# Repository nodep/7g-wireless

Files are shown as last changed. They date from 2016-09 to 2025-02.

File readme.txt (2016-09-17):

This project implements a replacement wireless keyboard controller which can be plugged into the SteelSeries 7G keyboard in place of the original controller.

The controller is designed around an Atmel ATMega169A. It communicates with the USB dongle (nRF24LU1+) using the nRF24L01+ 2.4GHz radio transceiver.

With aggressive power optimizations I have achieved an average consumption of 20 μA on the keyboard controller. It can run 6 to 10 years on two low self-discharge AA batteries or a year on a single CR2032 lithium cell. The USB dongle implements a standard HID keyboard. The keyboard also has a driverless configuration menu.

The dongle code can be compiled with sdcc (Small Device C Compiler) and the keyboard controller with avr-gcc.

The controller schematic and PCB are designed with EagleCAD.

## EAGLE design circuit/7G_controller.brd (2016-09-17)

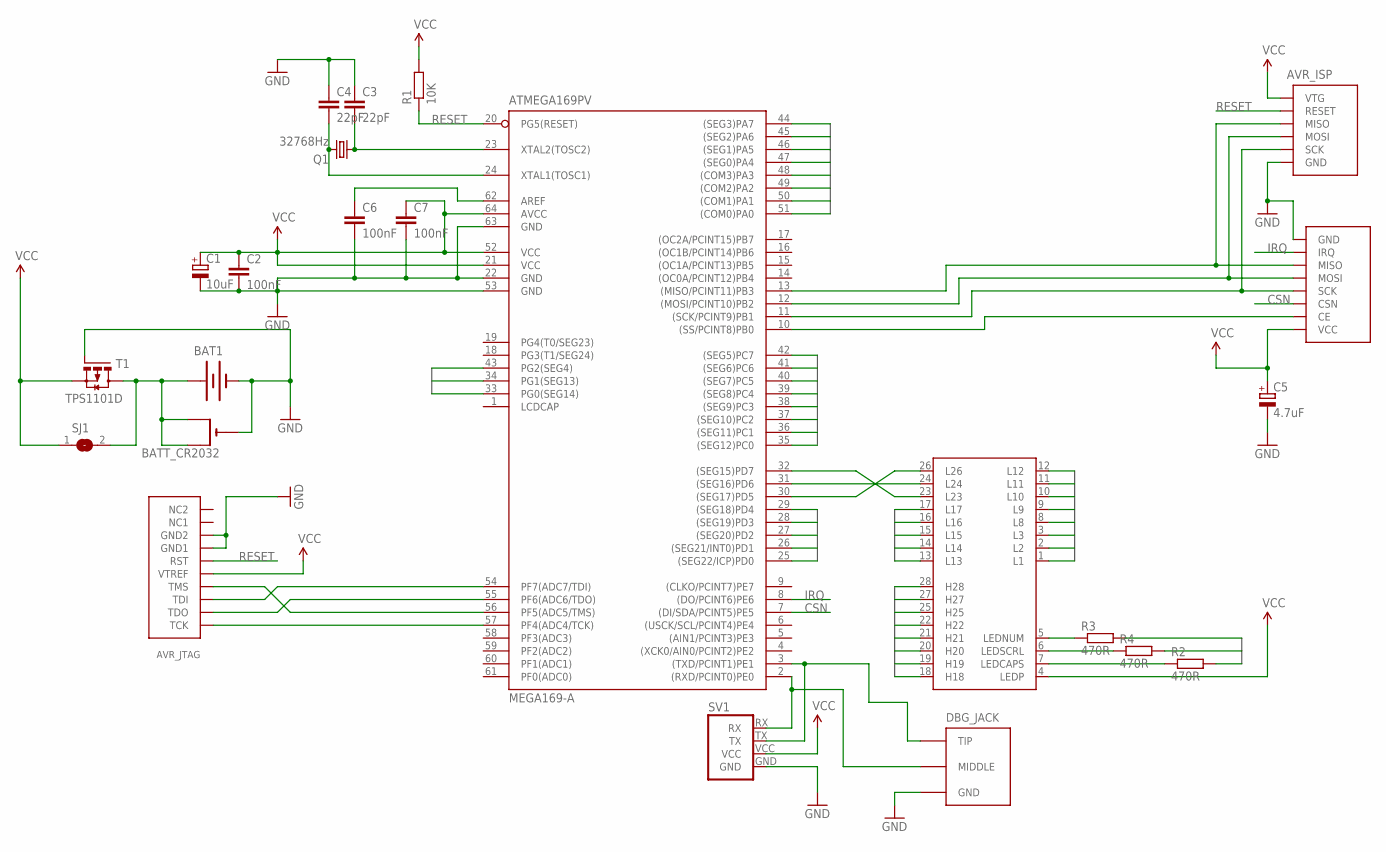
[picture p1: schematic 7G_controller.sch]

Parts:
ATMEGA169PV: MEGA169-A; TQFP64
AVR_ISP: AVR-ISP-6SMALL_FP; AVR-ISP-6-SMALL-FP
AVR_JTAG: AVR-JTAG
BAT1: BATTERYPLAIN; BATTERY
BATT_CR2032: CR2032SMT; CR2032-SMD
C1: 10uF; SMC_B
C2, C6, C7: 100nF; C0805
C3, C4: 22pF; C0805
C5: 4.7uF; SMC_B
DBG_JACK: JACK_FEMALE_3.5MMCHEAP; JACK_CHEAP
MTRX_CONN: SS7G_CONNSMD; SS7G_CONN_SMD
NRF24L01: NRF24L01_MOD_NINE_EAGLESGENERIC; NRF24L01_MOD_GENERIC
Q1: 32768Hz; NSK_QUARTZ_CLOCK
R1: 10K; R0805
R2, R3, R4: 470R; R0805
SJ1: SJ
SV1: UART_PORT
T1: TPS1101D; SO8

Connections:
AREF: ATMEGA169PV.62 (AREF), C6.1
CAPS: ATMEGA169PV.43 (PG2(SEG4)), R2.2
CE: ATMEGA169PV.10 ((SS/PCINT8)PB0), NRF24L01.CE
CSN: ATMEGA169PV.7 ((DI/SDA/PCINT5)PE5), NRF24L01.CSN
GND: ATMEGA169PV.22 (GND), ATMEGA169PV.53 (GND), ATMEGA169PV.63 (GND), AVR_ISP.GND, AVR_JTAG.P$2 (GND1), AVR_JTAG.P$10 (GND2), BAT1.-, BATT_CR2032.-, C1.-, C2.2, C3.1, C4.1, C5.-, C6.2, C7.2, DBG_JACK.1 (GND), NRF24L01.GND, SV1.GND, T1.4 (G)
H18: ATMEGA169PV.42 ((SEG5)PC7), MTRX_CONN.18 (H18)
H19: ATMEGA169PV.41 ((SEG6)PC6), MTRX_CONN.19 (H19)
H20: ATMEGA169PV.40 ((SEG7)PC5), MTRX_CONN.20 (H20)
H21: ATMEGA169PV.38 ((SEG9)PC3), MTRX_CONN.21 (H21)
H22: ATMEGA169PV.36 ((SEG11)PC1), MTRX_CONN.22 (H22)
H25: ATMEGA169PV.35 ((SEG12)PC0), MTRX_CONN.25 (H25)
H27: ATMEGA169PV.37 ((SEG10)PC2), MTRX_CONN.27 (H27)
H28: ATMEGA169PV.39 ((SEG8)PC4), MTRX_CONN.28 (H28)
IRQ: ATMEGA169PV.8 ((DO/PCINT6)PE6), NRF24L01.IRQ
L1: ATMEGA169PV.50 ((COM1)PA1), MTRX_CONN.1 (L1)
L2: ATMEGA169PV.48 ((COM3)PA3), MTRX_CONN.2 (L2)
L3: ATMEGA169PV.46 ((SEG1)PA5), MTRX_CONN.3 (L3)
L8: ATMEGA169PV.45 ((SEG2)PA6), MTRX_CONN.8 (L8)
L9: ATMEGA169PV.44 ((SEG3)PA7), MTRX_CONN.9 (L9)
L10: ATMEGA169PV.25 ((SEG22/ICP)PD0), MTRX_CONN.10 (L10)
L11: ATMEGA169PV.26 ((SEG21/INT0)PD1), MTRX_CONN.11 (L11)
L12: ATMEGA169PV.27 ((SEG20)PD2), MTRX_CONN.12 (L12)
L13: ATMEGA169PV.28 ((SEG19)PD3), MTRX_CONN.13 (L13)
L14: ATMEGA169PV.29 ((SEG18)PD4), MTRX_CONN.14 (L14)
L15: ATMEGA169PV.51 ((COM0)PA0), MTRX_CONN.15 (L15)
L16: ATMEGA169PV.49 ((COM2)PA2), MTRX_CONN.16 (L16)
L17: ATMEGA169PV.47 ((SEG0)PA4), MTRX_CONN.17 (L17)
LEDCAPS: MTRX_CONN.7 (LEDCAPS), R2.1
LEDNUM: MTRX_CONN.6 (LEDSCRL), R4.1
LEDSCRL: MTRX_CONN.5 (LEDNUM), R3.1
MISO: ATMEGA169PV.13 ((MISO/PCINT11)PB3), AVR_ISP.MISO, NRF24L01.MISO
MOSI: ATMEGA169PV.12 ((MOSI/PCINT10)PB2), AVR_ISP.MOSI, NRF24L01.MOSI
unnamed: ATMEGA169PV.32 ((SEG15)PD7), MTRX_CONN.23 (L23)
unnamed: BAT1.+, BATT_CR2032.+$1 (+), BATT_CR2032.+$2 (+1), SJ1.2, T1.5 (D), T1.6 (D), T1.7 (D), T1.8 (D)
unnamed: ATMEGA169PV.23 (XTAL2(TOSC2)), C3.2, Q1.1
unnamed: ATMEGA169PV.24 (XTAL1(TOSC1)), C4.2, Q1.4 (2)
unnamed: ATMEGA169PV.30 ((SEG17)PD5), MTRX_CONN.26 (L26)
unnamed: ATMEGA169PV.31 ((SEG16)PD6), MTRX_CONN.24 (L24)
unnamed: ATMEGA169PV.2 ((RXD/PCINT0)PE0), DBG_JACK.4 (MIDDLE), SV1.RX
unnamed: ATMEGA169PV.3 ((TXD/PCINT1)PE1), DBG_JACK.2 (TIP), DBG_JACK.3 (TIP), SV1.TX
NUML: ATMEGA169PV.33 (PG0(SEG14)), R3.2
RESET: ATMEGA169PV.20 (PG5(RESET)), AVR_ISP.RESET, AVR_JTAG.P$6 (RST), R1.1
SCK: ATMEGA169PV.11 ((SCK/PCINT9)PB1), AVR_ISP.SCK, NRF24L01.SCK
SCRL: ATMEGA169PV.34 (PG1(SEG13)), R4.2
TCK: ATMEGA169PV.57 (PF4(ADC4/TCK)), AVR_JTAG.P$1 (TCK)
TDI: ATMEGA169PV.54 (PF7(ADC7/TDI)), AVR_JTAG.P$9 (TDI)
TDO: ATMEGA169PV.55 (PF6(ADC6/TDO)), AVR_JTAG.P$3 (TDO)
TMS: ATMEGA169PV.56 (PF5(ADC5/TMS)), AVR_JTAG.P$5 (TMS)
VCC: ATMEGA169PV.21 (VCC), ATMEGA169PV.52 (VCC), ATMEGA169PV.64 (AVCC), AVR_ISP.VCC (VTG), AVR_JTAG.P$4 (VTREF), C1.+, C2.1, C5.+, C7.1, MTRX_CONN.4 (LEDP), NRF24L01.+3.3V (VCC), R1.2, SJ1.1, SV1.VCC, T1.1 (S), T1.2 (S), T1.3 (S)

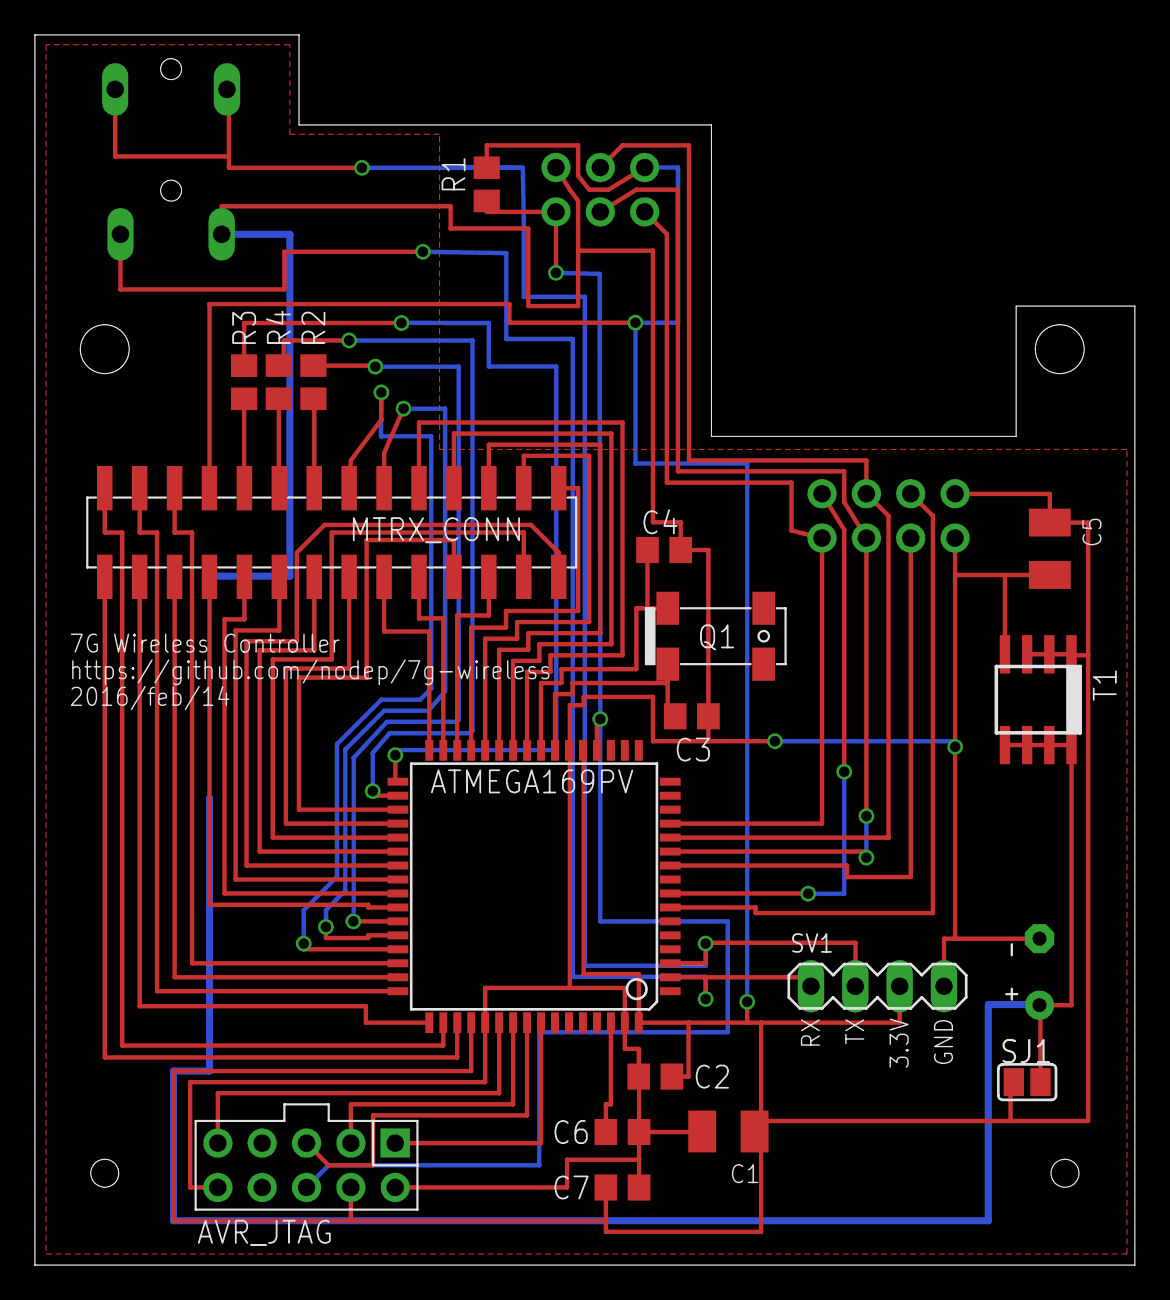
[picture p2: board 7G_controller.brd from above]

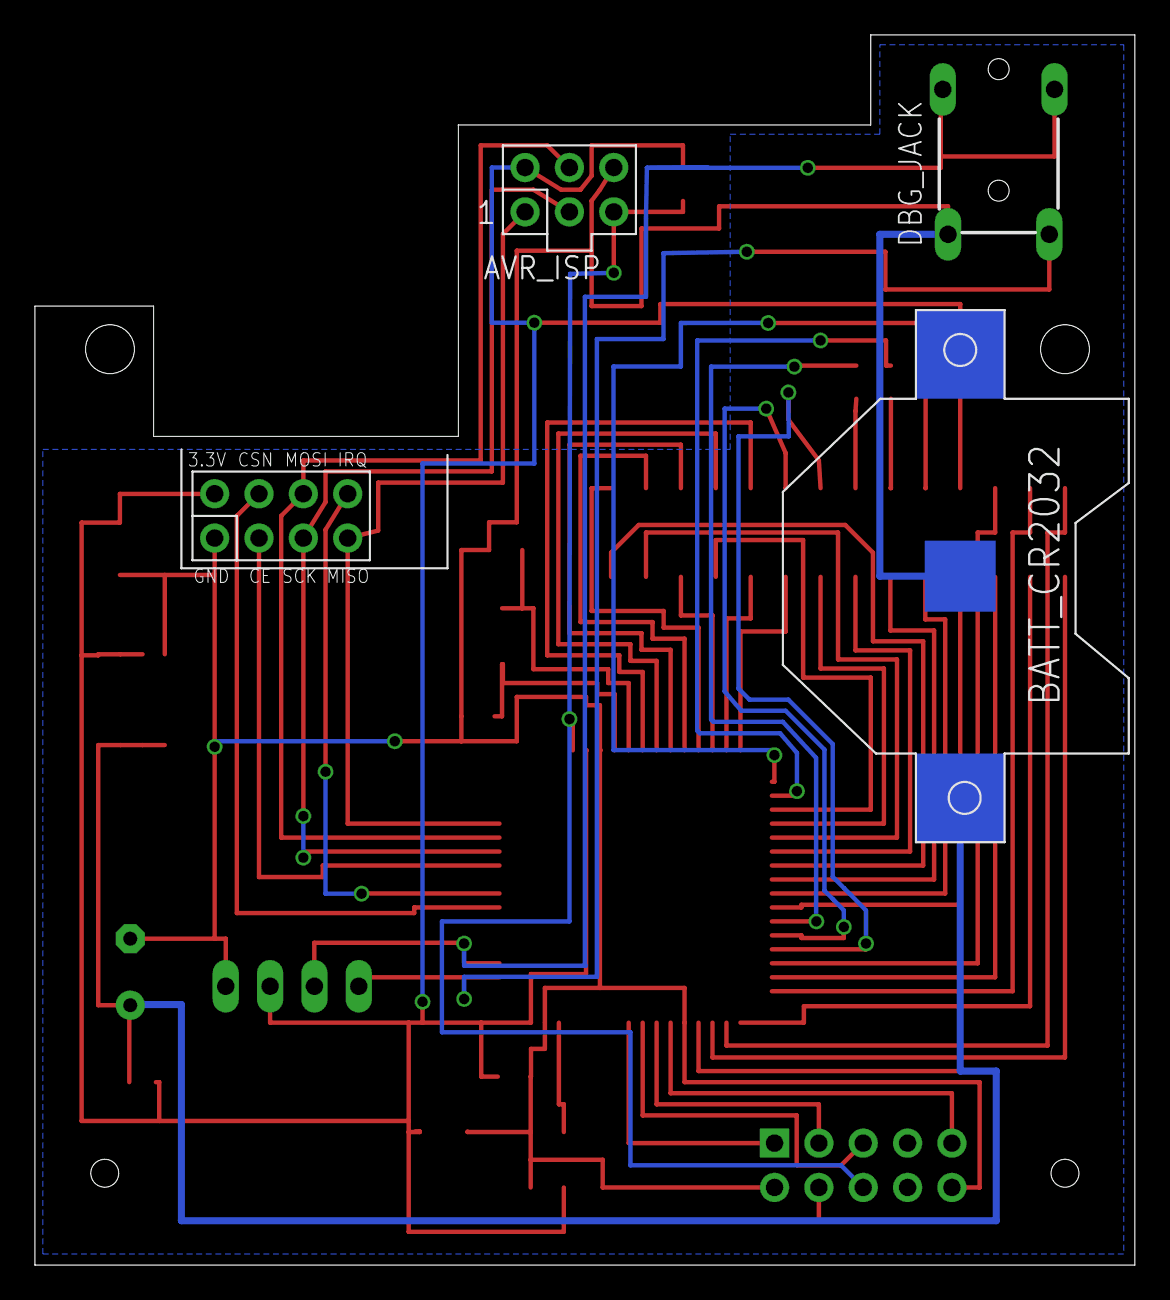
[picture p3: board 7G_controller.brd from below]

Board: 2 copper layers, 63.0 x 70.5 mm, 23 parts (4 on the bottom side), 49 nets.

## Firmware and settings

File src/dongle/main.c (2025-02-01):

#include <stdbool.h>
#include <stdio.h>
#include <stdint.h>
#include <string.h>

#include "reg24lu1.h"

#include "keycode.h"
#include "text_message.h"
#include "reports.h"
#include "rf_protocol.h"
#include "rf_dngl.h"
#include "nrfutils.h"

#include "usb.h"
#include "usb_regs.h"

#include "nrfdbg.h"
#include "leds.h"

__xdata void* memcpy_X(__xdata void* dest, __xdata const void* src, size_t count)
{
	__xdata char* dst8 = (__xdata char*)dest;
	__xdata const char* src8 = (__xdata const char*)src;

	while (count--)
		*dst8++ = *src8++;

	return dest;
}

void* memcpy_P(__xdata void* dest, __code const void* src, size_t count)
{
	char* dst8 = (char*)dest;
	char* src8 = (char*)src;

	while (count--)
		*dst8++ = *src8++;

	return dest;
}

#define RECV_BUFF_SIZE		32

void main()
{
	bool keyboard_report_ready = false;
	bool consumer_report_ready = false;

	uint8_t prev_keycode = KC_NO;
	uint8_t modifier_step = 0;
	
	__xdata uint8_t recv_buffer[RECV_BUFF_SIZE];
	__xdata uint8_t bytes_received;
	
	P0DIR = 0x00;	// all outputs
	P0ALT = 0x00;	// all GPIO default behavior
	
	LED_off();

	usbInit();
	//dbgInit();
	
	rf_dngl_init();

	reset_keyboard_report();
	
	for (;;)
	{
		usbPoll();	// handles USB interrupts
		//dbgPoll();	// send chars from the uart TX buffer
		
		// try to read the recv buffer
		bytes_received = rf_dngl_recv(recv_buffer, RECV_BUFF_SIZE);

		if (bytes_received)
		{
			// we have new data, so what is it?
			if (recv_buffer[0] == MT_KEY_STATE)
			{
				process_key_state_msg(recv_buffer, bytes_received);

				consumer_report_ready = true;
				keyboard_report_ready = true;
			} else if (recv_buffer[0] == MT_TEXT) {
				process_text_msg(recv_buffer, bytes_received);
			}
		}

		if (!keyboard_report_ready  &&  !msg_empty())
		{
			// peek the next char from the stored text message
			uint8_t c = msg_peek();
			uint8_t new_keycode = get_keycode_for_char(c);
			uint8_t new_modifiers = get_modifiers_for_char(c);

			reset_keyboard_report();

			// Linux seems to be a bit finicky when it comes to the order in the which the keys and
			// modifiers are received. So we have to do a keystroke sequence to get the desired result
	        if (new_modifiers != 0)
	        {
				if (modifier_step == 0)
				{
					// no keys are down
	                ++modifier_step;
				}
	            else if (modifier_step == 1)
	            {
					// sends KC_NO and the modifier
	                usb_keyboard_report.modifiers = new_modifiers;
	                ++modifier_step;
	            }
	            else if (modifier_step == 2)
	            {
					// sends the keystroke and the modifier
	                usb_keyboard_report.keys[0] = new_keycode;
	                usb_keyboard_report.modifiers = new_modifiers;
	                ++modifier_step;
	            }
	            else if (modifier_step == 3)
	            {
					// sends KC_NO and the modifier
	                usb_keyboard_report.modifiers = new_modifiers;
	                ++modifier_step;
	            }
	            else if (modifier_step == 4)
				{
					// no keys are down
	                modifier_step = 0;
	                msg_pop();	// remove char from the buffer
				}
	        }
	        else if (new_keycode != prev_keycode  ||  new_keycode == KC_NO)
	        {
	            usb_keyboard_report.keys[0] = new_keycode;
	            usb_keyboard_report.modifiers = new_modifiers;

	            msg_pop();	// remove char from the buffer
	        } else {
	            new_keycode = KC_NO;
	        }			
			prev_keycode = new_keycode;
			keyboard_report_ready = true;
		}
		
		// send the report if the endpoint is not busy
		if ((in1cs & 0x02) == 0   &&   (keyboard_report_ready  ||  usbHasIdleElapsed()))
		{
			// copy the keyboard report into the endpoint buffer
			in1buf[0] = usb_keyboard_report.modifiers;
			in1buf[1] = 0;
			in1buf[2] = usb_keyboard_report.keys[0];
			in1buf[3] = usb_keyboard_report.keys[1];
			in1buf[4] = usb_keyboard_report.keys[2];
			in1buf[5] = usb_keyboard_report.keys[3];
			in1buf[6] = usb_keyboard_report.keys[4];
			in1buf[7] = usb_keyboard_report.keys[5];

			// send the data on it's way
			in1bc = 8;
			
			keyboard_report_ready = false;
		}

		// send the consumer report if the endpoint is not busy
		if ((in2cs & 0x02) == 0   &&   (consumer_report_ready  ||  usbHasIdleElapsed()))
		{
			in2buf[0] = usb_consumer_report;
			in2bc = 1;
		
			consumer_report_ready = false;
		}
	}
}

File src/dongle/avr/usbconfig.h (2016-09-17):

/* Name: usbconfig.h
 * Project: V-USB, virtual USB port for Atmel's(r) AVR(r) microcontrollers
 * Author: Christian Starkjohann
 * Creation Date: 2005-04-01
 * Tabsize: 4
 * Copyright: (c) 2005 by OBJECTIVE DEVELOPMENT Software GmbH
 * License: GNU GPL v2 (see License.txt), GNU GPL v3 or proprietary (CommercialLicense.txt)
 */

#ifndef __usbconfig_h_included__
#define __usbconfig_h_included__

/*
General Description:
This file is an example configuration (with inline documentation) for the USB
driver. It configures V-USB for USB D+ connected to Port D bit 2 (which is
also hardware interrupt 0 on many devices) and USB D- to Port D bit 4. You may
wire the lines to any other port, as long as D+ is also wired to INT0 (or any
other hardware interrupt, as long as it is the highest level interrupt, see
section at the end of this file).
+ To create your own usbconfig.h file, copy this file to your project's
+ firmware source directory) and rename it to "usbconfig.h".
+ Then edit it accordingly.
*/

/* ---------------------------- Hardware Config ---------------------------- */

#define USB_CFG_IOPORTNAME      D
/* This is the port where the USB bus is connected. When you configure it to
 * "B", the registers PORTB, PINB and DDRB will be used.
 */
#define USB_CFG_DMINUS_BIT      3
/* This is the bit number in USB_CFG_IOPORT where the USB D- line is connected.
 * This may be any bit in the port.
 */
#define USB_CFG_DPLUS_BIT       2
/* This is the bit number in USB_CFG_IOPORT where the USB D+ line is connected.
 * This may be any bit in the port. Please note that D+ must also be connected
 * to interrupt pin INT0! [You can also use other interrupts, see section
 * "Optional MCU Description" below, or you can connect D- to the interrupt, as
 * it is required if you use the USB_COUNT_SOF feature. If you use D- for the
 * interrupt, the USB interrupt will also be triggered at Start-Of-Frame
 * markers every millisecond.]
 */
#define USB_CFG_CLOCK_KHZ       (F_CPU/1000)
/* Clock rate of the AVR in kHz. Legal values are 12000, 12800, 15000, 16000,
 * 16500, 18000 and 20000. The 12.8 MHz and 16.5 MHz versions of the code
 * require no crystal, they tolerate +/- 1% deviation from the nominal
 * frequency. All other rates require a precision of 2000 ppm and thus a
 * crystal!
 * Since F_CPU should be defined to your actual clock rate anyway, you should
 * not need to modify this setting.
 */
#define USB_CFG_CHECK_CRC       0
/* Define this to 1 if you want that the driver checks integrity of incoming
 * data packets (CRC checks). CRC checks cost quite a bit of code size and are
 * currently only available for 18 MHz crystal clock. You must choose
 * USB_CFG_CLOCK_KHZ = 18000 if you enable this option.
 */

/* ----------------------- Optional Hardware Config ------------------------ */

#define USB_CFG_PULLUP_IOPORTNAME   D
/* If you connect the 1.5k pullup resistor from D- to a port pin instead of
 * V+, you can connect and disconnect the device from firmware by calling
 * the macros usbDeviceConnect() and usbDeviceDisconnect() (see usbdrv.h).
 * This constant defines the port on which the pullup resistor is connected.
 */
#define USB_CFG_PULLUP_BIT          4
/* This constant defines the bit number in USB_CFG_PULLUP_IOPORT (defined
 * above) where the 1.5k pullup resistor is connected. See description
 * above for details.
 */

/* --------------------------- Functional Range ---------------------------- */
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

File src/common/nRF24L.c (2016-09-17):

#include <stdint.h>

#ifndef AVR
#  ifdef NRF24LE1
#    include <reg24le1.h>
#  elif defined(NRF24LU1)
#    include <reg24lu1.h>
#  endif
#endif

#include "nRF24L.h"

uint8_t __xdata nRF_data[MAX_COMMAND_LENGTH];

#ifdef AVR

void nRF_Init(void)
{
#ifdef NRF_PWR_PORT
	// the 3.3v voltage regulator
	SetBit(DDR(NRF_PWR_PORT), NRF_PWR_BIT);
	ClrBit(PORT(NRF_PWR_PORT), NRF_PWR_BIT);

	nRF_Reset();
#endif

	ClrBit(DDR(NRF_IRQ_PORT), NRF_IRQ_BIT);		// input pin
	SetBit(PORT(NRF_IRQ_PORT), NRF_IRQ_BIT);	// enable pull-up

	// if SS pin is defined, set it as output
	// to prevent SPI going into slave mode
#ifdef NRF_SS_PORT
	SetBit(DDR(NRF_SS_PORT), NRF_SS_BIT);
#endif	
	
	// set the CSN and CE as output pins
	SetBit(DDR(NRF_CSN_PORT), NRF_CSN_BIT);
	SetBit(DDR(NRF_CE_PORT), NRF_CE_BIT);

	// set these to default states
    nRF_CE_lo();
    nRF_CSN_hi();

	// init SPI pins
    SetBit(DDR(NRF_MOSI_PORT), NRF_MOSI_BIT);	// outputs
    SetBit(DDR(NRF_SCK_PORT), NRF_SCK_BIT);
	ClrBit(DDR(NRF_MISO_PORT), NRF_MISO_BIT);	// input

	// enable SPI in Master Mode with SCK = CK/4
	SetVal(SPCR, _BV(SPE) | _BV(MSTR));

	SPSR;	// clear SPIF bit in SPSR
	SPDR;
}

#else

void nRF_Init(void)
{
#ifdef NRF24LU1
	// LE1 has the internal SPI enabled all the time
	RFCTL = 0x11;	// enable SPI, 1/2 clock
#endif
	RFCON = 0x04;	// enable RF clock, CSN low, CE low
}

#endif

static uint8_t nRF_SpiShiftByte(uint8_t byte)
{
#ifdef AVR		
	SPDR = byte;		// set byte to send the nRF through MOSI
	loop_until_bit_is_set(SPSR, SPIF);	// wait until char is sent
	byte = SPDR;		// remember the byte received from nRF through MISO
#else

# ifdef NRF24LE1

	SPIRDAT = byte;		// set byte to send the nRF through the internal MOSI
	
	// wait while there is data in the internal SPI fifo
	while ((SPIRSTAT & (uint8_t)0x02U) == 0)
		;
		
	byte = SPIRDAT;		// remember the byte received from nRF through MISO
	
# elif defined(NRF24LU1)

	RFDAT = byte;		// set byte to send the nRF through the internal MOSI
	RFSPIF = 0;			// reset the RF SPI interrupt flag
	while (!RFSPIF)		// wait for byte to finish
		;
	byte = RFDAT;		// remember the byte received from nRF through MISO
	
# endif

#endif		

	return byte;
}

static uint8_t nRF_ShiftCommand(uint8_t cmd_len)
{
	uint8_t* pData = nRF_data;
	
	nRF_CSN_lo();

	while (cmd_len > 0)
	{
		*pData = nRF_SpiShiftByte(*pData);
		++pData;
		--cmd_len;
	}

	nRF_CSN_hi();

	// return status register
	return *nRF_data;
}

uint8_t nRF_ShiftByte(const uint8_t one_byte)
{
	nRF_CSN_lo();

	// remember the byte received from nRF through miso
	*nRF_data = nRF_SpiShiftByte(one_byte);

	nRF_CSN_hi();

	// return the STATUS register
	return *nRF_data;
}

uint8_t nRF_ReadReg(const enum nRFRegister_e reg)
{
	nRF_data[0] = R_REGISTER | reg;

	return nRF_ShiftCommand(2);
}

uint8_t nRF_WriteReg(const enum nRFRegister_e reg, const uint8_t val)
{
	nRF_data[0] = W_REGISTER | reg;
	nRF_data[1] = val;

	return nRF_ShiftCommand(2);
}

uint8_t nRF_WriteAddrReg(const enum nRFRegister_e reg, const uint8_t __code * addr, const uint8_t addr_len)
{
	uint8_t c;
	
	nRF_data[0] = W_REGISTER | reg;

	// set the data to be sent
	for (c = 0; c < addr_len; c++)
		nRF_data[1 + c] = addr[c];

	return nRF_ShiftCommand(addr_len + 1);
}

uint8_t nRF_ReadAddrReg(const enum nRFRegister_e reg, const uint8_t addr_len)
{
	nRF_data[0] = R_REGISTER | reg;

	return nRF_ShiftCommand(addr_len + 1);
}

uint8_t nRF_ReadRxPayload(const uint8_t num_bytes)
{
	nRF_data[0] = R_RX_PAYLOAD;

	return nRF_ShiftCommand(num_bytes + 1);
}

uint8_t nRF_WriteTxPayload(const uint8_t* payload, const uint8_t num_bytes)
{
	uint8_t c;
	
	nRF_data[0] = W_TX_PAYLOAD;

	// set the data to be sent
	for (c = 0; c < num_bytes; c++)
		nRF_data[1 + c] = payload[c];

	return nRF_ShiftCommand(num_bytes + 1);
}

uint8_t nRF_ReuseTxPayload(void)
{
	return nRF_ShiftByte(REUSE_TX_PL);
}

uint8_t nRF_FlushTX(void)
{
	return nRF_ShiftByte(FLUSH_TX);
}

uint8_t nRF_FlushRX(void)
{
	return nRF_ShiftByte(FLUSH_RX);
}

uint8_t nRF_NOP(void)
{
	return nRF_ShiftByte(NOP);
}

uint8_t nRF_ReadRxPayloadWidth(void)
{
	nRF_data[0] = R_RX_PL_WID;

	return nRF_ShiftCommand(2);
}

uint8_t nRF_WriteAckPayload(const uint8_t __xdata * payload, const uint8_t num_bytes, const uint8_t pipe_num)
{
	uint8_t c;

	nRF_data[0] = W_ACK_PAYLOAD | pipe_num;

	// set the data to be sent
	for (c = 0; c < num_bytes; c++)
		nRF_data[1 + c] = payload[c];

	return nRF_ShiftCommand(num_bytes + 1);
}

#ifdef NRF_PWR_PORT

void nRF_Reset(void)
{
	// First turn off all the output pins and the pull-up resistors of the input pins
	// of the ATmega that are used to communicate with the nRF module.
	// If these are left on, the nRF will not reset. I am not sure why this is, but
	// I'm guessing it's because in this case the nRF chip is powered through the pull-up
	// resistors on the input pins of the nRF.

	ClrBit(PORT(NRF_IRQ_PORT), NRF_IRQ_BIT);		// pull-up
	ClrBit(PORT(NRF_CE_PORT), NRF_CE_BIT);			// output
	ClrBit(PORT(NRF_CSN_PORT), NRF_CSN_BIT);		// output
	ClrBit(PORT(NRF_MOSI_PORT), NRF_MOSI_BIT);		// output
	ClrBit(PORT(NRF_MISO_PORT), NRF_MISO_BIT);		// pull-up
	ClrBit(PORT(NRF_SCK_PORT), NRF_SCK_BIT);		// output

	// Now turn the voltage regulator off
	ClrBit(PORT(NRF_PWR_PORT), NRF_PWR_BIT);

	// Wait for the voltage regulator output filtering capacitor to discharge.
	// I got this duration using the program below
	_delay_ms(200);

	// turn the pull-ups and the outputs back on
	SetBit(PORT(NRF_IRQ_PORT), NRF_IRQ_BIT);		// pull-up
	ClrBit(PORT(NRF_MOSI_PORT), NRF_MOSI_BIT);		// output
	SetBit(PORT(NRF_MISO_PORT), NRF_MISO_BIT);		// pull-up
	ClrBit(PORT(NRF_SCK_PORT), NRF_SCK_BIT);		// output

    nRF_CE_lo();
    nRF_CSN_hi();

	// turn the voltage regulator back on
	SetBit(PORT(NRF_PWR_PORT), NRF_PWR_BIT);

	// wait for the chip to wake up and the voltage to stabilize
	_delay_ms(50);
}

#endif	// NRF_PWR_PORT

/*
// this can be used to find the duration that is necessary to keep the nRF's
// voltage regulator in the off state to reset the nRF chip.
void main(void)
{
	init_serial();	// UART is currently only used for debugging
	init_hw();
	nRF_Init();

	// the main send loop
	const uint8_t TestAddr[] = {0x12, 0x34, 0x56, 0x78, 0x90};
	const uint16_t MAX_LOOP = 50;

	uint16_t ms_off, cloop;
	uint8_t reset, not_reset;

	for (ms_off = 110; ms_off < 500; ms_off++)
	{
		printf("testing with: %4ums  ", ms_off);

		reset = not_reset = 0;

		for (cloop = 0; cloop < MAX_LOOP  &&  not_reset < 5; cloop++)
		{
			nRF_WriteAddrReg(TX_ADDR, TestAddr, 5);	// write the address

			nRF_Reset(ms_off);

			nRF_ReadAddrReg(TX_ADDR, 5);			// read the address back

			if (nRF_data[1] == TestAddr[0])
				++not_reset;
			else
				++reset;
		}

		printf("reset/NOT reset: %u/%u\n", reset, not_reset);

		if (not_reset == 0)
			break;
	}

	if (not_reset != 0)
		printf("off duration not found. Increse upper limit of ms_off loop value\n");
	else
		printf("Off duration found: %ums\n", ms_off);

	for (;;)
		;
}
*/

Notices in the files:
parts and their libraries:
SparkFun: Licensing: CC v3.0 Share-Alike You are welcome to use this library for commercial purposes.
